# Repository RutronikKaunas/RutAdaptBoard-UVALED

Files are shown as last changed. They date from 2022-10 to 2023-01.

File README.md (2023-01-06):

# RutAdaptBoard-UVA LED Odor Eliminator

This is an odor-eliminator concept. The ultra-high frequency PWM is used to generate UVA light Trichel pulses that are exposing the TiO2 catalyst. The VOC – Volatile Organic Compounds are degrading on the TiO2 catalyst surface down to the harmless and odorless components.

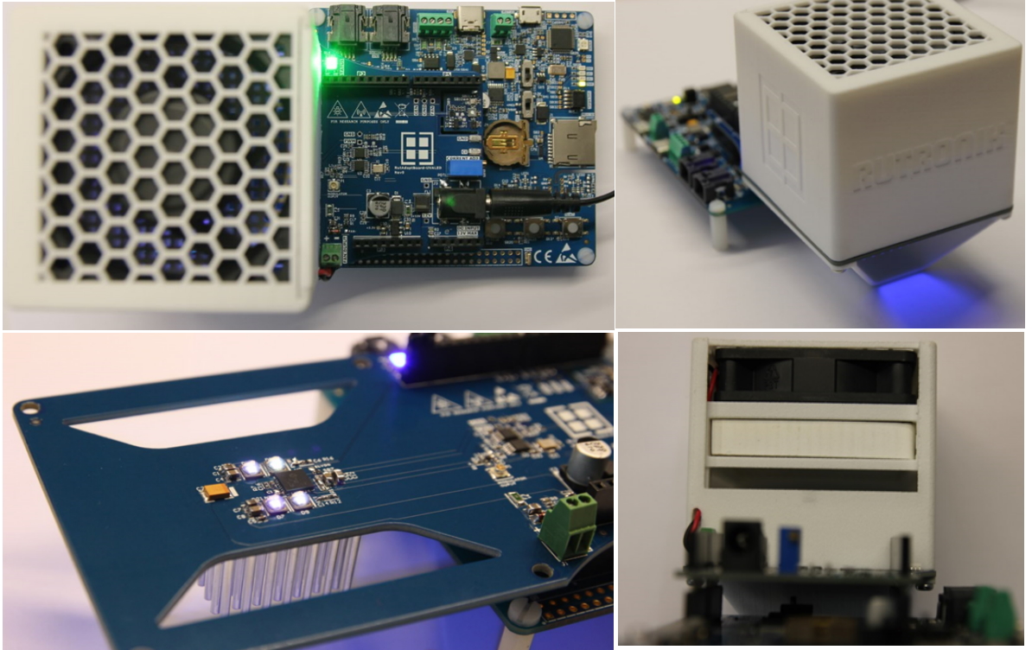
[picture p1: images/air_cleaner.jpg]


## Features

-  iC-HG 200MHz 3A LASER Switch.

-  High Power UVA-LEDs NDU1104ESE-405-TR from Stanley Electric.

-  SI5351A-B-GT - I2C Progrmmable Clock Generator IC.

-  SHTC1 - Sensirion's Humidity and Temperature Sensor IC.

-  SGP30 - Sensirion's Indoor Air Quality Sensor for TVOC and CO2eq Measurements.

-  BMP388 - Digital pressure sensor from BOSCH.

-  DG2733EDQ-T1-GE3 - Low Voltage Dual SPDT Analog Switch from Vishay.

-  AZ1117CR-3.3TRG1 - 3.3V 800mA LDo from Diodes Inc.

-  The heat sink : „ICK S 25*25*18.5“ from Fischer Elektronik.

-  Liteon LTPL- R6060BSH titanium dioxide photocatalyst filter.

-  Delta AFB0612HHB - Fan for airflow control and air cooling of the LEDs.

## Legal Disclaimer

The evaluation board including the software is for testing purposes only and, because it has limited functions and limited resilience, is not suitable for permanent use under real conditions. If the evaluation board is nevertheless used under real conditions, this is done at one’s responsibility; any liability of Rutronik is insofar excluded. 

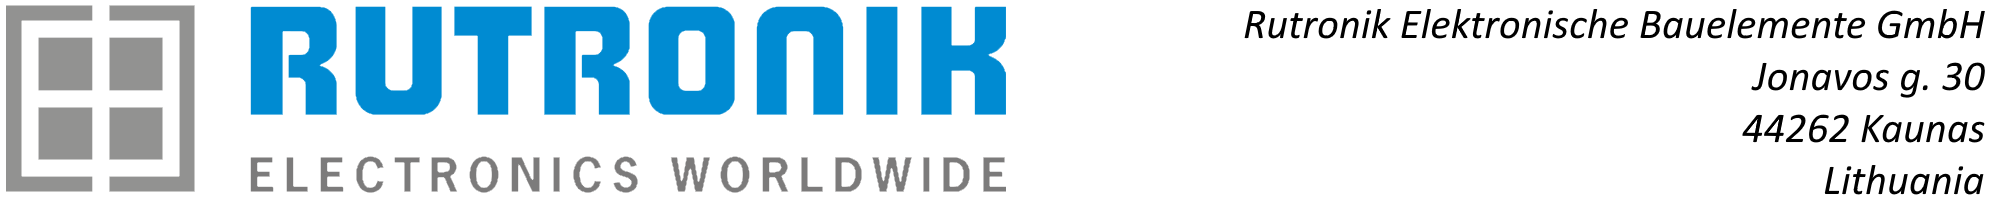
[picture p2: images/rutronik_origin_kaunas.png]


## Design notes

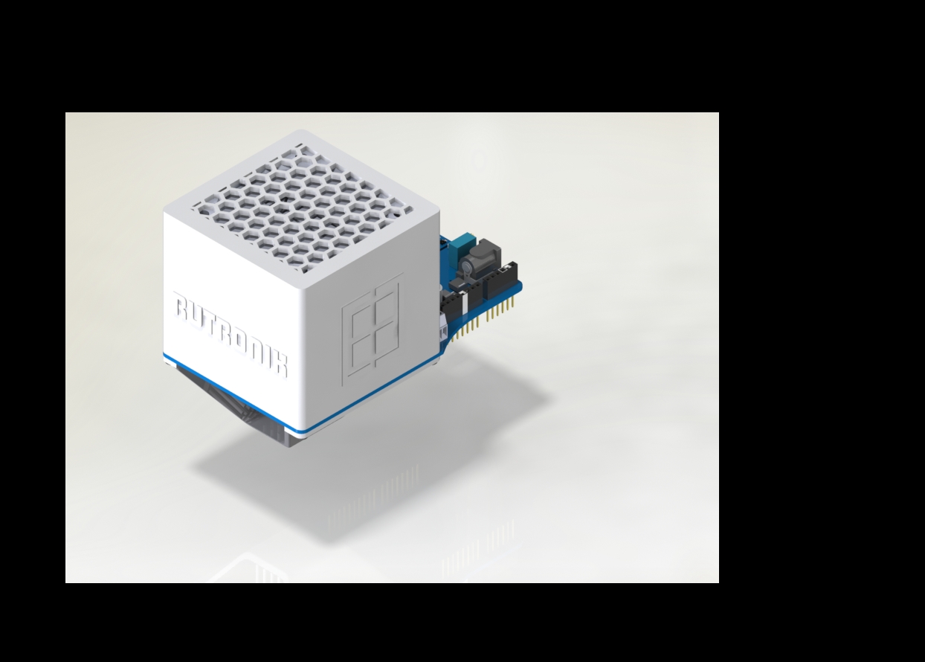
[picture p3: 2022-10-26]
Hardware Design Files/RutAdaptBoard-UVALED Housing/Render/Studio rendering.JPG

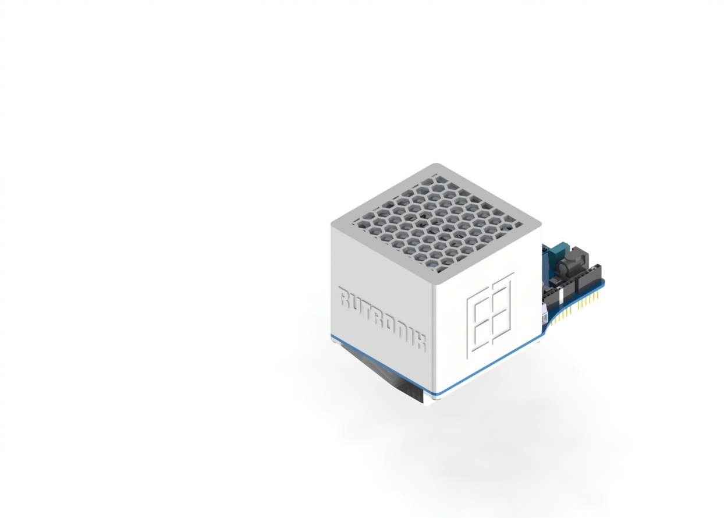
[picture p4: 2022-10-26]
Hardware Design Files/RutAdaptBoard-UVALED Housing/Render/Soft box view.JPG

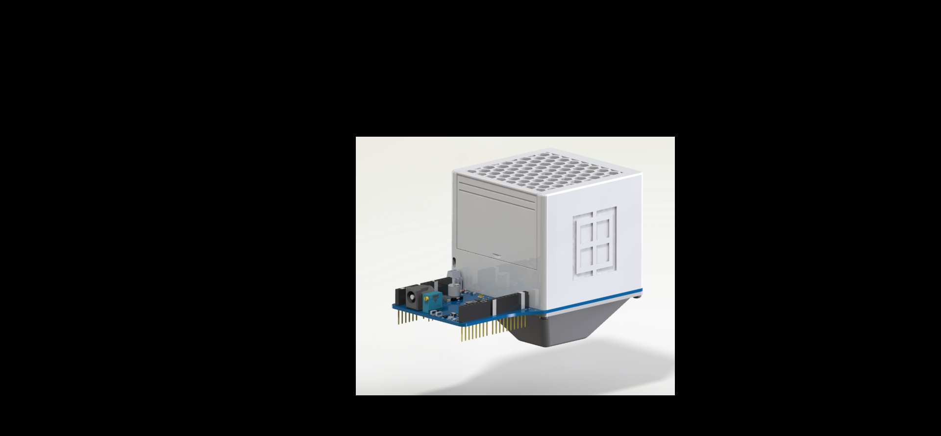
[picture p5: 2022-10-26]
Hardware Design Files/RutAdaptBoard-UVALED Housing/Render/final render_1.JPG

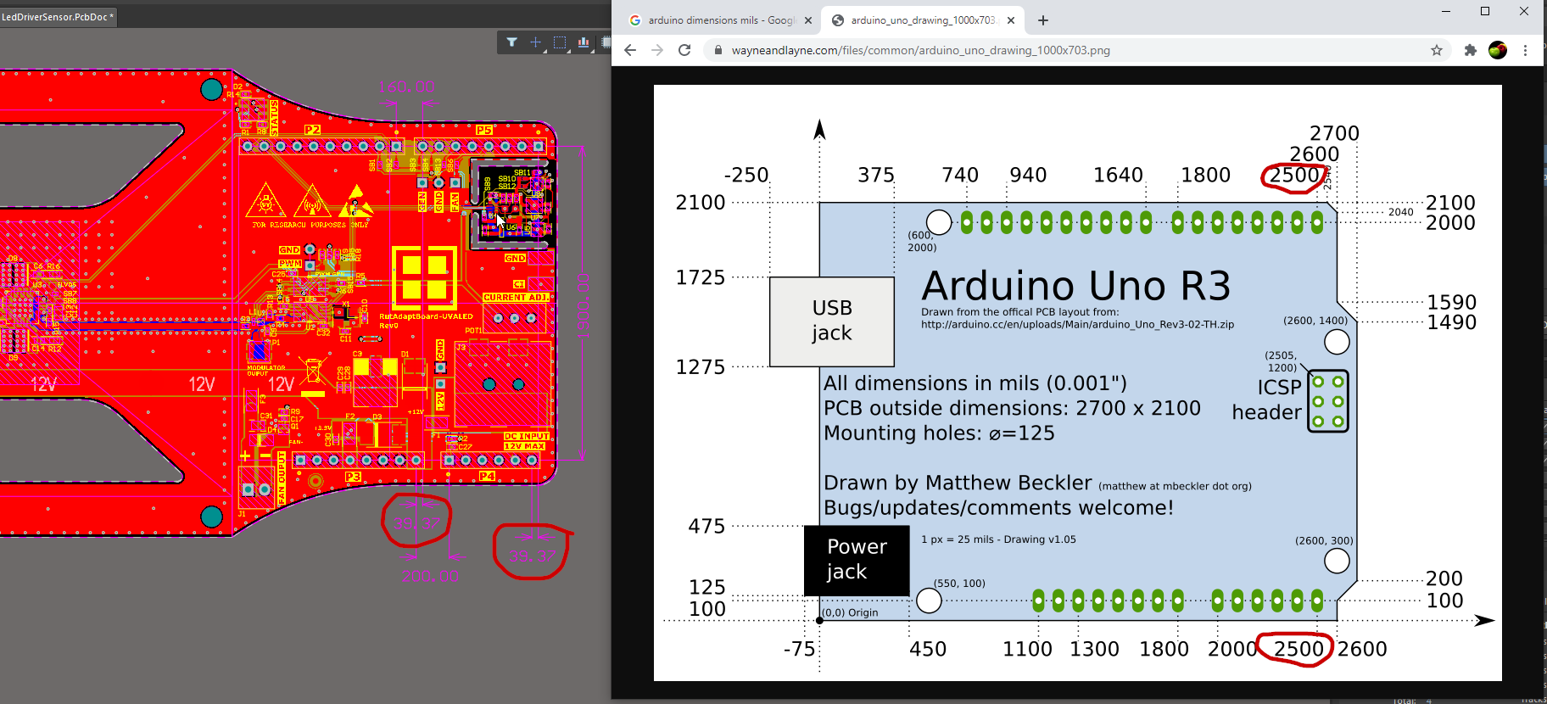
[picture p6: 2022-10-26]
Hardware Design Files/RutAdaptBoard-UVALED Housing/Arduino dimmensions.png

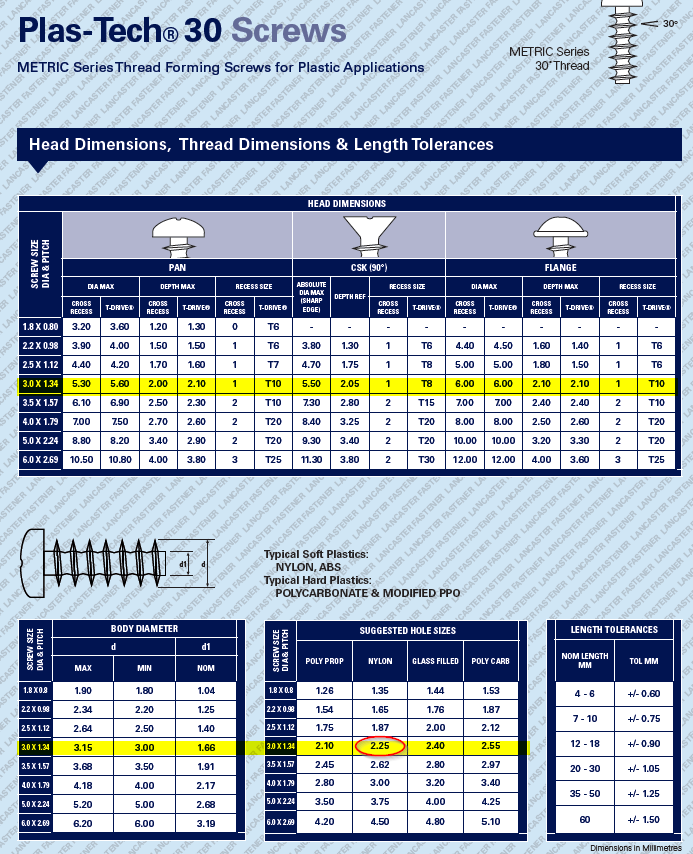
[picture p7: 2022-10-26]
Hardware Design Files/RutAdaptBoard-UVALED Housing/Documentation/Plastech 30 hole size .png

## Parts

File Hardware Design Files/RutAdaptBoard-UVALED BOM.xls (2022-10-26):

RUTADAPTBOARD-UVALED BOM Rev0
Part Description | Specification | Value | Designator | Footprint | Quantity | Manufacturer | Manufacturer Part No. | Supplier | Supplier part number | Link
Ceramic Capacitor | X7R, 16V, 10% | 10uF | C1, C7, C12, C30, C31 | C0805 | 5 | Samsung EM | CL21B106KOQNNNG | Rutronik | KKS2640 | https://www.rutronik24.com/product/samsung+em/cl21b106koqnnng/32265.html
Ceramic Capacitor | X7R, 16V, 10% | 100nF | C2, C5, C9, C13, C15, C16, C18, C19, C20, C23, C24, C25, C27, C28, C32 | C0402 | 15 | Samsung EM | CL05B104KO5NNNC | Rutronik | KKK21419 | https://www.rutronik24.com/product/samsung+em/cl05b104ko5nnnc/4748662.html
Electrolytic Capacitor | 16V, 20% | 330uF | C3 | Cap_6.3_7.7_SMD | 1 | Panasonic | EEE-FTC331XAP | Rutronik | KEL20909 | https://www.rutronik24.com/search-result/qs:EEE-FTC331XAP/reset:0
Ceramic Capacitor | X7R, 16V, 10% | 1uF | C4, C8, C33, C34 | C0805 | 4 | Samsung EM | CL21B105KOFNNNF | Rutronik | KKK16216 | https://www.rutronik24.com/product/samsung+em/cl21b105kofnnnf/30238.html
Ceramic Capacitor | NP0, 50V, 0.25pf | 2.2pF | C10, C11 | C0402 | 2 | Yageo | CC0402CRNPO9BN2R2 | Rutronik | KKK19155 | https://www.rutronik24.com/product/yageo/cc0402crnpo9bn2r2/30956.html
Ceramic Capacitor | NP0, 50V, 5% | 33pF | C17, C29 | C0402 | 2 | Samsung EM | CL05C330JB5NNNC | Rutronik | KKK15073 | https://www.rutronik24.com/product/samsung+em/cl05c330jb5nnnc/29970.html
Ceramic Capacitor | X5R, 16V, 10% | 1uF | C21, C22 | C0402 | 2 | Samsung EM | CL05A105KO5NNNC | Rutronik | KKS1052 | https://www.rutronik24.com/product/samsung+em/cl05a105ko5nnnc/31788.html
Tantalum Polymer Capacitor | 16V, 20% | 33uF | C26 | Case-B | 1 | AVX | TCNL336M016R0200E | Rutronik | TCNL336M016R0200E | https://www.rutronik24.com/search-result/qs:TCNL336M016R0200E/reset:0
TVS Diode | 14V, 0.6kW | SMBJ12A-13-F | D1 | DO-214AA | 1 | Diodes Inc. | SMBJ12A-13-F | Rutronik | DTRL10413 | https://www.rutronik24.com/product/diodes+inc/smbj12a-13-f/10283804.html
RGB LED | 626 nm, 528 nm, 465 nm | LRTBGVSR-U4V2-JW+A6BB-D8+S2U2-7Z-20-S | D2 | PlCC6_led avago | 1 | OSRAM | LRTBGVSR-U4V2-JW+A6BB-D8+S2U2-7Z-20-S | Rutronik | LRTBGVSR-U4V2-JW+A6BB-D8+S2U2-7Z-20-S | https://www.osram.com/ecat/OSIRE%C2%AE%20E3635%20LRTBGVSR/com/en/class_pim_web_catalog_103489/global/prd_pim_device_5154412/
High Power UV-LED | UVA, 405nm, 500mA | NDU1104ESE-405-TR | D5, D7, D8, D9 | NDU1104ESE | 4 | Stanley Electric | NDU1104ESE-405-TR | Rutronik | IR7213 | https://www.rutronik24.com/product/stanley/ndu1104ese-405-tr/12405034.html
High I²t Chip fuse | 32V, 5A | CC12H5A-TR | F1 | R1206 | 1 | EATON | CC12H5A-TR | Rutronik | FUSE7161 | https://www.rutronik24.com/search-result/nojs:1337/qs:CC12H5A-TR/reset:0
High I²t Chip fuse | 63V, 1A | CC12H1A-TR | F3 | R1206 | 1 | EATON | CC12H1A-TR | Rutronik | CC12H1A-TR | https://www.rutronik24.com/search-result/qs:CC12H1A-TR/reset:0
Wire Wound Chip Common Mode Choke Coil | 250R/100MHz | DLW5BTM251SQ2L | FL1 | DLW5BTM | 1 | MuRata | DLW5BTM251SQ2L | Rutronik | IND12787 | https://www.rutronik24.com/product/murata/dlw5btm251sq2l/4718370.html
Pin heatsink quadratic | 25 x 25 x 18,5 mm | ICK S 25x25x18,5 | HS1 | ICKS25x25x18_5 | 1 | Fischer Elektronik | ICK S 25x25x18,5 | Rutronik | HSINK2003 | https://www.rutronik24.com/product/fischer/ick+s+25+x+25+x+18%2C5/12693988.html
Terminal | 2pos. 2.54mm, 12A | MSD02004 | J1 | SAURO_2POS_2.54 | 1 | SAURO | MSD02004 | Rutronik | CONN2626 | https://www.rutronik24.com/search-result/nojs:1337/qs:MSD02004/reset:0
Low Voltage Power Supply Connector | 20V, 5A | ADC-028-1-T/R-PA10T | J3 | DC_JACK_ADC-028-1 | 1 | ADAM TECH | ADC-028-1-T/R-PA10T | Rutronik | CONN1349 | https://www.rutronik24.com/search-result/qs:ADC-028-1/reset:0
Inductor | 150mA 5% | 100nH | L1 | L0402 | 1 | muRata | LQG15WHR10J02D | Rutronik | LQG15WHR10J02D | https://www.rutronik24.com/search-result/qs:LQG15WHR10J02D/reset:0
U.FL Connector | Male | U.FL-R-SMT-1(10) | P1 | U.FL_Connector_Male | 1 | HIROSE | U.FL-R-SMT-1(10) | Rutronik | COREC23028 | https://www.hirose.com/product/en/products/U.FL/U.FL-R-SMT-1%2810%29/
Arduino Connector | 10 pos. 2,54mm | RS1-10-G-413 | P2 | HDR1X10_ARDUINO | 1 | ADAM TECH | RS1-10-G-413 | Rutronik | CONN1443 | http://www.adam-tech.com/products.php
Arduino Connector | 8 pos. 2,54mm | RS1-08-G-413 | P3, P5 | HDR1X8_ARDUINO | 2 | ADAM TECH | RS1-08-G-413 | Rutronik | CONN2043 | http://www.adam-tech.com/products.php
Arduino Connector | 6 pos. 2,54mm | RS1-06-G-413 | P4 | HDR1X6_ARDUINO | 1 | ADAM TECH | RS1-06-G-413 | Rutronik | CONN2042 | http://www.adam-tech.com/products.php
Trimmer | 10% 0,5W | 10K | POT1 | T93XA | 1 | Vishay | T93XA103KT20 | Rutronik | T93XA103KT20 | https://www.rutronik24.com/search-result/qs:T93XA103KT20/reset:0
N-Channel MOSFET | 20V, 0.63A | DMG1012T-7 | Q1 | SOT-523_custom | 1 | Diodes Inc. | DMG1012T-7 | Rutronik | TMOSS6623 | https://www.rutronik24.com/product/diodes+inc/dmg1012t-7/5168665.html
Thick Film Resistor | 5% 0,063W | 220R | R1, R8, R14 | R0402 | 3 | ASJ | RC0402JR-0710KL | Rutronik | WRC35108 | https://www.rutronik24.com/product/asj/cr10-221-jk/51883.html
Thick Film Resistor | 5% 0,063W | 10K | R2, R9, R18, R19 | R0402 | 4 | ASJ | CR10-103-JK | Rutronik | WRC40976 | https://www.rutronik24.com/product/asj/cr10-103-jk/54295.html
Thick Film Resistor | 5% 0,063W | 0R | R3, R4 | R0402 | 2 | Yageo | RC04020R | Rutronik | WRC52534 | https://www.rutronik24.com/product/yageo/ac0402fr-070rl/1082692.html
Thick Film Resistor | 5% 0,063W | 4.7K | R5, R6 | R0402 | 2 | Yageo | RC0402JR-134K7L | Rutronik | WRC46913 | https://www.rutronik24.com/product/yageo/rc0402jr-134k7l/56100.html
Thick Film Resistor | 5% 0,063W | 1K | R7 | R0402 | 1 | Yageo | RC0402JR-071KL | Rutronik | WRC33833 | https://www.rutronik24.com/search-result/nojs:1337/qs:RC0402JR-071KL/reset:0
NTC Thermistor | 3% 0,1W | NTCG103UH103HT1 | R21 | 0402NTC | 1 | TDK | NTCG103UH103HT1 | Rutronik | NTCG103UH103HT1 | https://www.rutronik24.com/search-result/qs:NTCG103UH103HT1/reset:0
Thick Film Resistor | 5% 0,063W | 0R | SB1, SB2, SB5, SB6, SB7, SB9, SB11, SB13 | SB_0402 | 8 | Yageo | RC04020R | Rutronik | WRC52534 | https://www.rutronik24.com/product/yageo/ac0402fr-070rl/1082692.html
SMT Test Point | 3.81*2.03 | 5019 | TP2, TP3 | 5019_keystone | 2 | Keystone Electrincs | 5019 | Rutronik | BAT4950 | https://www.rutronik24.com/product/keystone/pn5019/7028403.html
2-Input AND Gate | 3.3V, 2.5ns | 7UL1G08FS,LF | U1 | SOT-953 | 1 | TOSHIBA | 7UL1G08FS,LF | Rutronik | 7UL1G08FSLFCT-ND | https://toshiba.semicon-storage.com/ap-en/semiconductor/product/general-purpose-logic-ics/detail.7UL1G08FS.html
I2C-PROGRAMMABLE CLOCK | 200MHz, 3.3V | SI5351A-B-GT | U2 | MSOP10 | 1 | Silicon Labs | SI5351A-B-GT | Digi-Key | 336-2399-5-ND | https://www.digikey.com/en/products/detail/silicon-labs/SI5351A-B-GT/3679847
3 A LASER SWITCH | 200MHz, 3A | iC-HG | U3 | QFN28-5x5 | 1 | iC Haus | iC-HG | Rutronik | iC-HG | https://www.ichaus.de/product/iC-HG
2-Bit Bi-directional Level Shifter | 8UDFN | PI4ULS5V202XVEX | U4 | UDFN1.2x1.6-8L | 1 | Diodes Inc. | PI4ULS5V202XVEX | Rutronik | PI4ULS5V202XVEX | https://www.diodes.com/part/view/PI4ULS5V202
Humidity and Temperature Sensor IC | 1.8V, I2C | SHTC1 | U5 | SHTC1 | 1 | Sensirion | SHTC1 | Rutronik | ICENVI1113 | https://www.rutronik24.com/product/sensirion/shtc1/9854425.html
150mA ULTRA-LOW QUIESCENT CURRENT LDO WITH ENABLE | 5.5V,1.8V,150mA | AP7354-18W5-7 | U6 | SOT23-5L | 1 | Diodes Inc. | AP7354-18W5-7 | Rutronik | AP7354-18W5-7 | https://www.rutronik24.com/search-result/qs:AP7354-18W5-7/reset:0
Indoor Air Quality Sensor for TVOC and CO2eq Measurements | 1.8V, I2C | SGP30 | U7 | SGP30 | 1 | Sensirion | SGP30 | Rutronik | ICENVI1053 | https://www.rutronik24.com/product/sensirion/sgp30/8537405.html
Digital pressure sensor | 1.8V, I2C, SPI | BMP388 | U8 | BMP388 | 1 | BOSCH | BMP388 | Rutronik | ICENVI1143 | https://www.rutronik24.com/product/bosch+se/bmp388/10280357.html
Low Voltage Dual SPDT Analog Switch | 0.3Ohm, Dual SPDT | DG2733EDQ-T1-GE3 | U9 | MSOP10 | 1 | Vishay | DG2733EDQ-T1-GE3 | Rutronik | DG2733EDQ-T1-GE3 | https://www.vishay.com/docs/75646/dg2535e_dg2733e.pdf
LOW DROPOUT LINEAR REGULATOR | 18V, 3.3V, 0.8A | AZ1117CR-3.3TRG1 | U10 | SOT89 | 1 | Diodes Inc. | AZ1117CR-3.3TRG1 | Rutronik | ICSPR9803 | https://www.rutronik24.com/search-result/qs:AZ1117CR-3.3TRG1/reset:0
XTAL 3.2x2.5mm | 25MHz, | C7M2500012AEHHF0-RE02 | X1 | XTAL_3.5x2.5 | 1 | HKC Europe | C7M2500012AEHHF0-RE02 | Rutronik | QUARZ6470 | https://www.rutronik24.com/product/hkc/c7m2500012aehhf0-re02/6739407.html

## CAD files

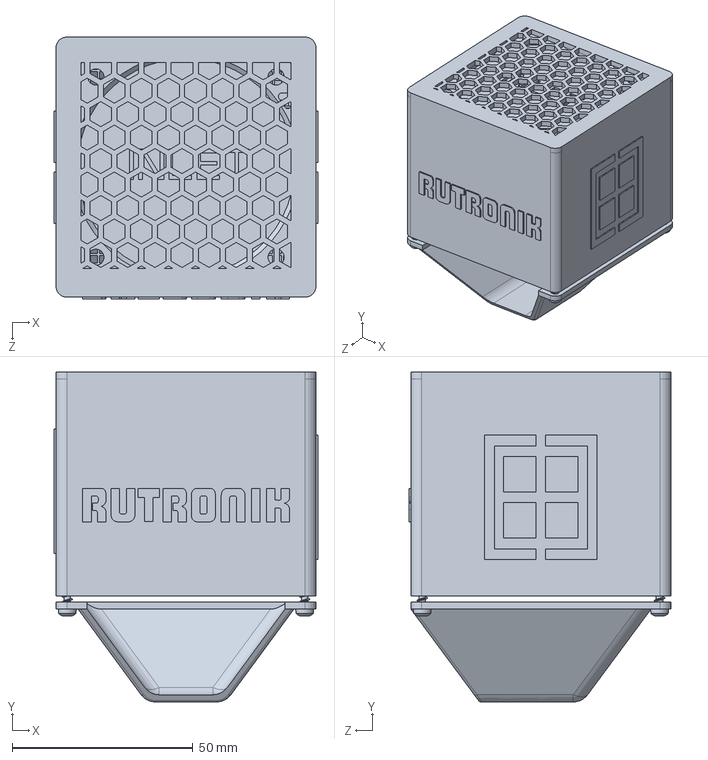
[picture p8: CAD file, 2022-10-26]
Hardware Design Files/RutAdaptBoard-UVALED Housing/Case_assembly_4altium.SLDPRT
73.0 x 91.3 x 72.5 mm

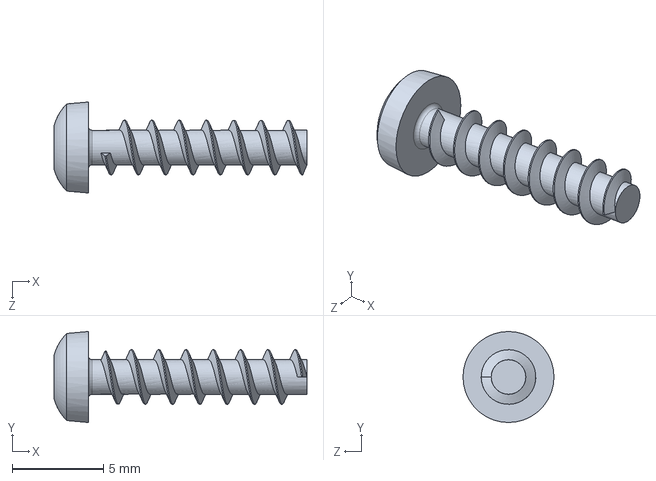
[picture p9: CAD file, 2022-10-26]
Hardware Design Files/RutAdaptBoard-UVALED Housing/TR Fastenings Ltd-3MMX12MM.SLDPRT
13.9 x 5.00 x 5.00 mm

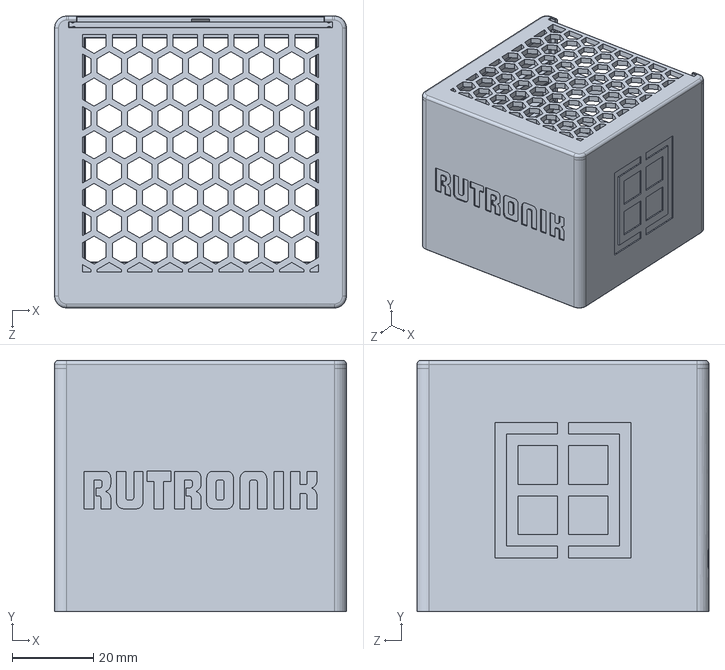
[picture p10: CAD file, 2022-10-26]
Hardware Design Files/RutAdaptBoard-UVALED Housing/Case.SLDPRT
72.0 x 62.0 x 72.0 mm

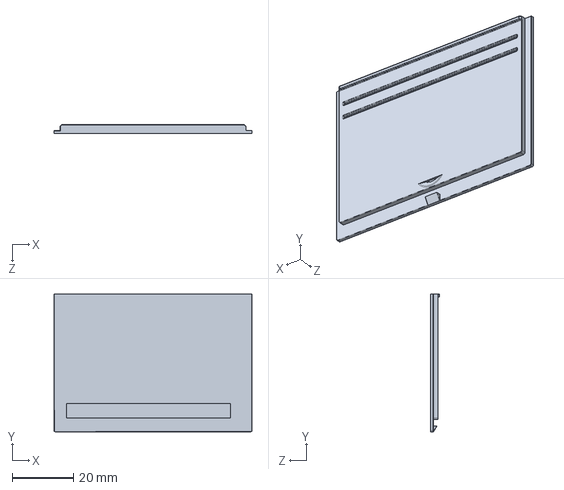
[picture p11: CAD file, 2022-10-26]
Hardware Design Files/RutAdaptBoard-UVALED Housing/LID.SLDPRT
64.6 x 45.0 x 3.00 mm

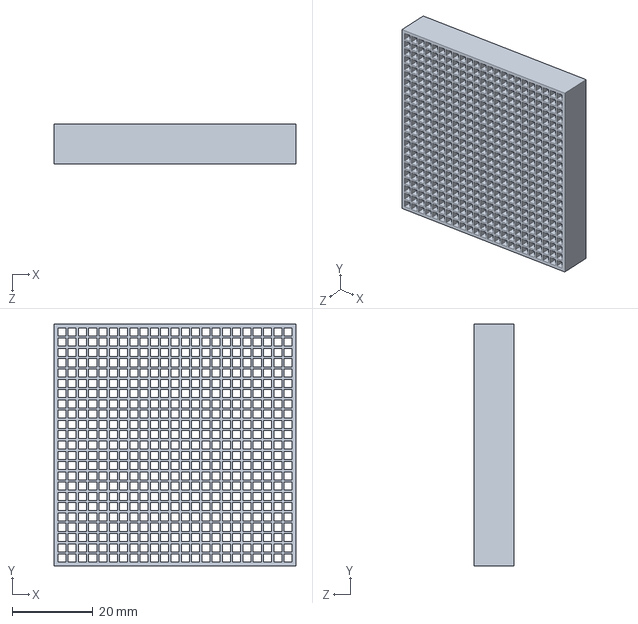
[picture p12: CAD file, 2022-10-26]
Hardware Design Files/RutAdaptBoard-UVALED Housing/LTPL-R6060BSH.SLDPRT
60.0 x 60.0 x 10.0 mm

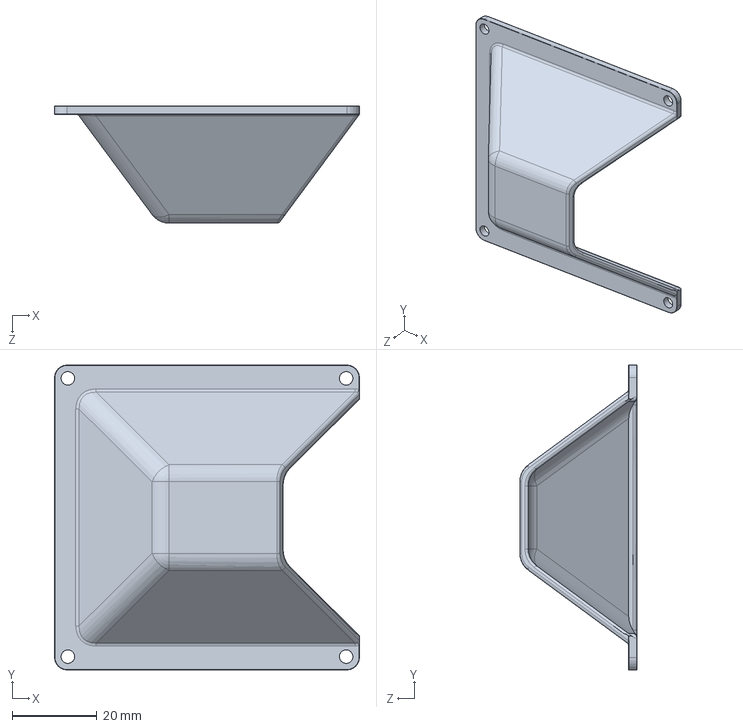
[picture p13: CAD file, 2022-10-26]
Hardware Design Files/RutAdaptBoard-UVALED Housing/Deflector.SLDPRT
72.0 x 72.0 x 27.7 mm

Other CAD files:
Hardware Design Files/RutAdaptBoard-UVALED Housing/Part4.SLDPRT
Hardware Design Files/RutAdaptBoard-UVALED Housing/Board-Part-1.SLDPRT
Hardware Design Files/RutAdaptBoard-UVALED Housing/3D print REV.0/Case.x_t
Hardware Design Files/RutAdaptBoard-UVALED Housing/3D print REV.0/Case_assembly_REV_0.x_t
Hardware Design Files/RutAdaptBoard-UVALED Housing/3D print REV.0/Deflector.x_t
Hardware Design Files/RutAdaptBoard-UVALED Housing/3D print REV.0/LID.x_t
Hardware Design Files/RutAdaptBoard-UVALED Housing/3D print REV0.1/Case.x_t
Hardware Design Files/RutAdaptBoard-UVALED Housing/3D print REV0.1/Deflector.x_t
Hardware Design Files/RutAdaptBoard-UVALED Housing/3D print REV0.1/LID.x_t
Hardware Design Files/RutAdaptBoard-UVALED Housing/Case.x_t
Hardware Design Files/RutAdaptBoard-UVALED Housing/Case_assembly_12.08.x_t
Hardware Design Files/RutAdaptBoard-UVALED Housing/Draw2.SLDDRW
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

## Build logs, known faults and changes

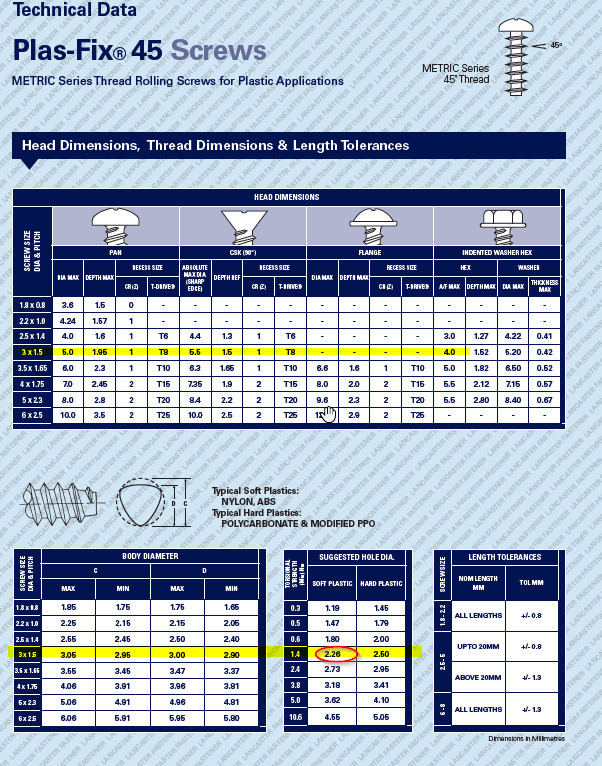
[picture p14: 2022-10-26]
Hardware Design Files/RutAdaptBoard-UVALED Housing/Documentation/Plas-Fix 45 hole size .png

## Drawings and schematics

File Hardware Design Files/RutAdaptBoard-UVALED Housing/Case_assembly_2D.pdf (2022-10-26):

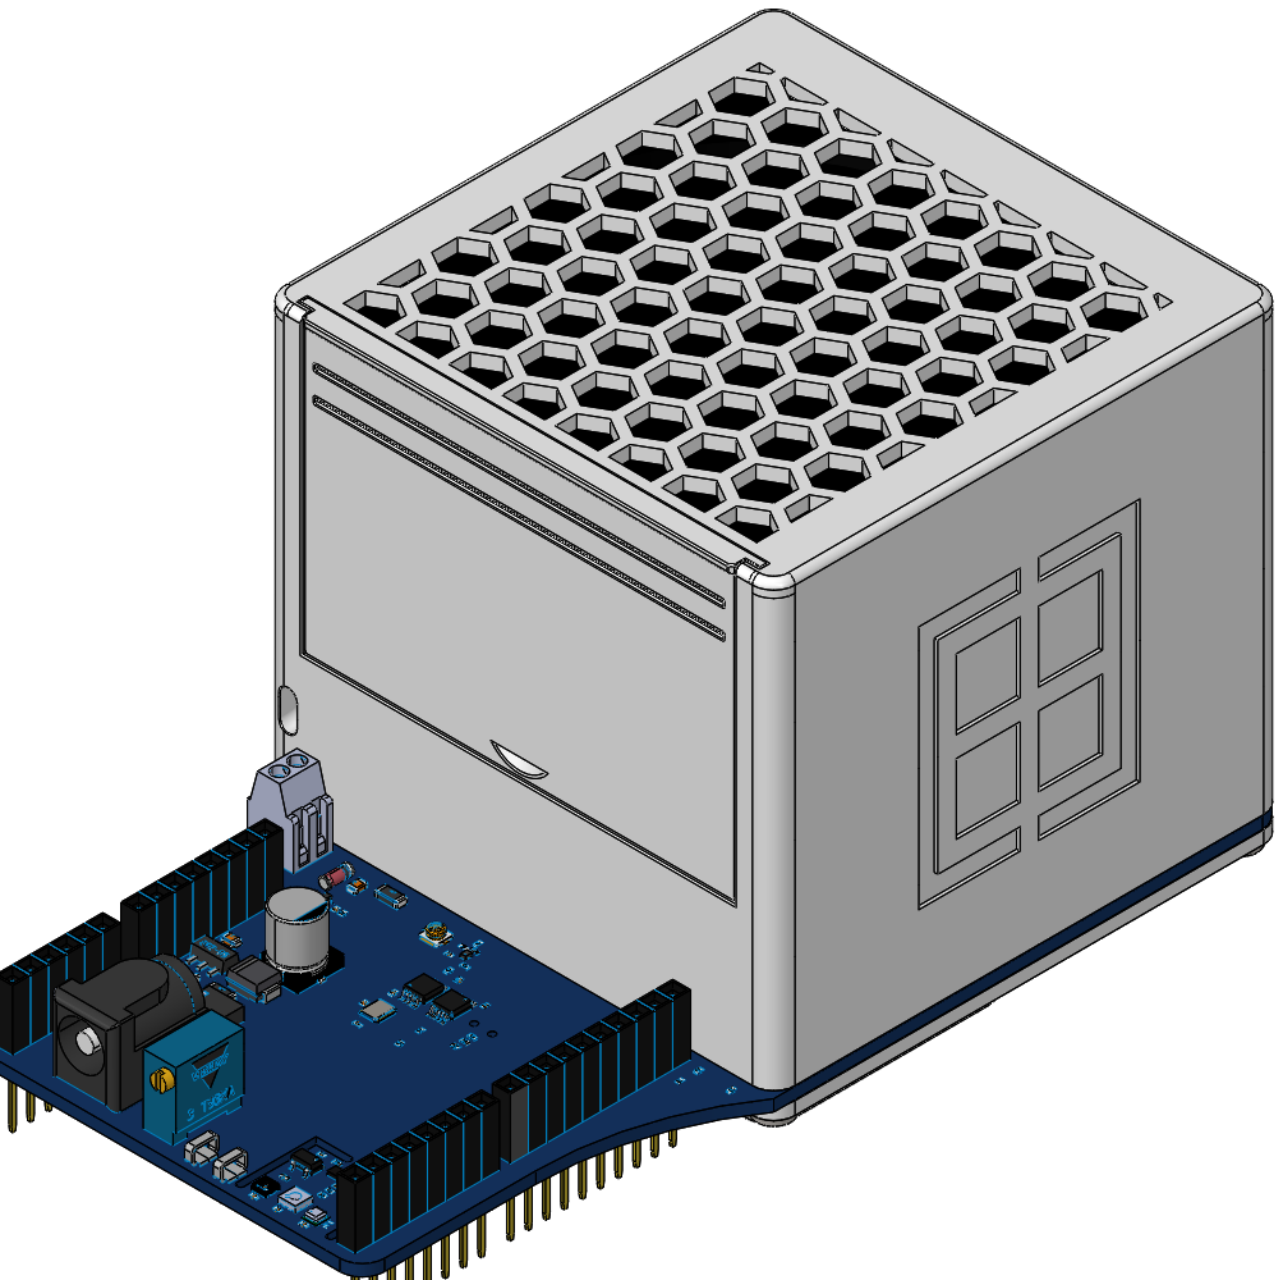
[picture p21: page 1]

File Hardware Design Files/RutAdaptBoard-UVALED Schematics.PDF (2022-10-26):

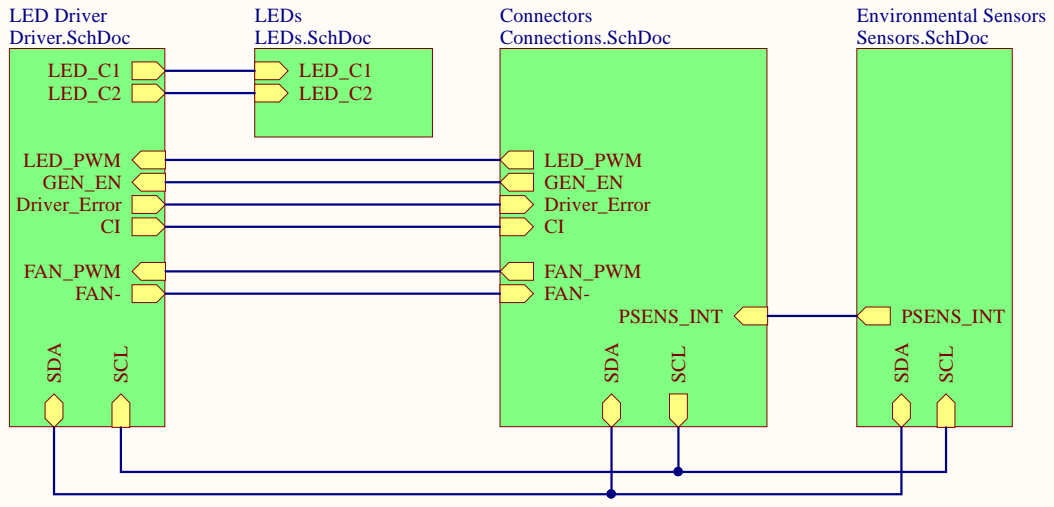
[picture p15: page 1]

RutAdaptBoard-UVProject_General Title | * * *

Size: A4 | Number: | Revision:
Date: 2020-12-03 Time: 13:52:15 | | Sheet of

C:\Users\gdr\Documents\GitHub\RutAppKit-LedDriverSensor\RutAppKit-LedDriverSensor\General.SchDot

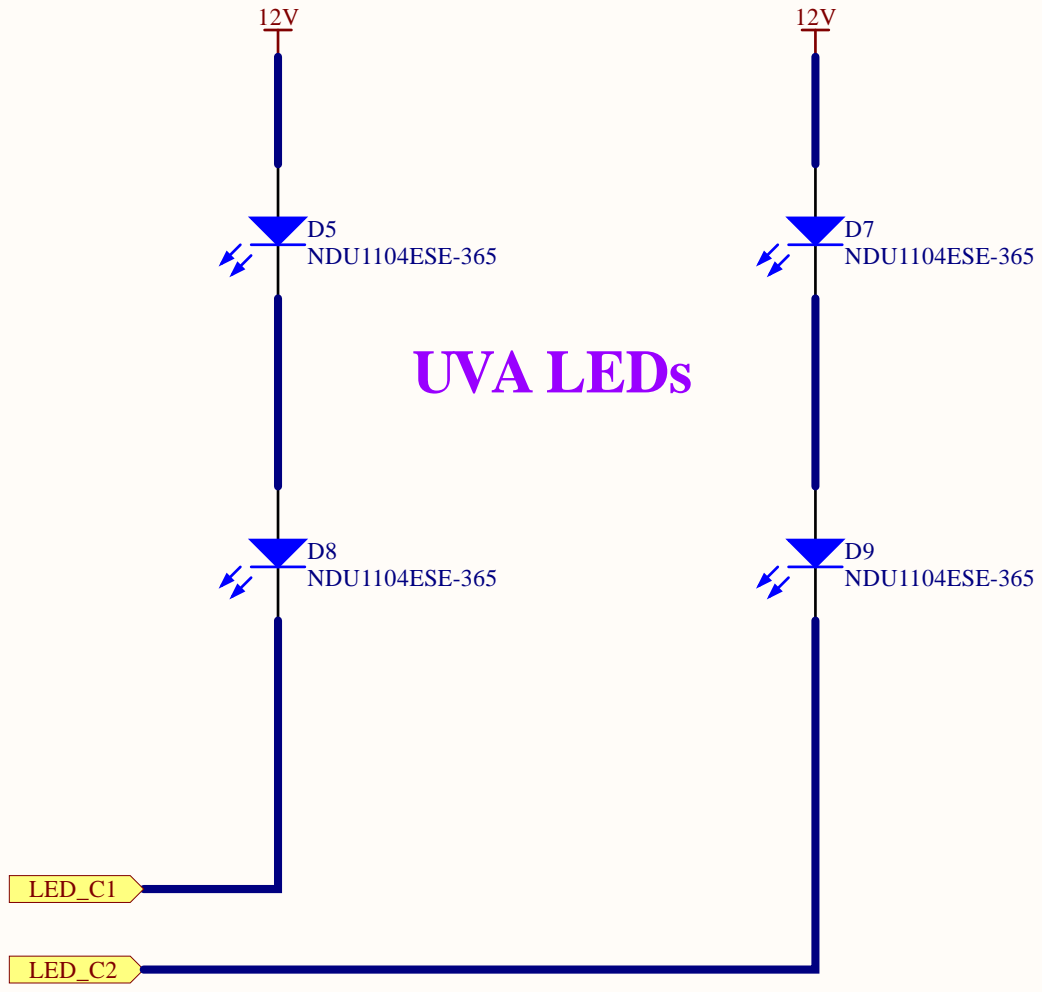
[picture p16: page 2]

LED s T i t l e | ****

Size: A | N umber: | Rev i s i o n :

0-1 2-0 T ime: : : | | Sheet o f

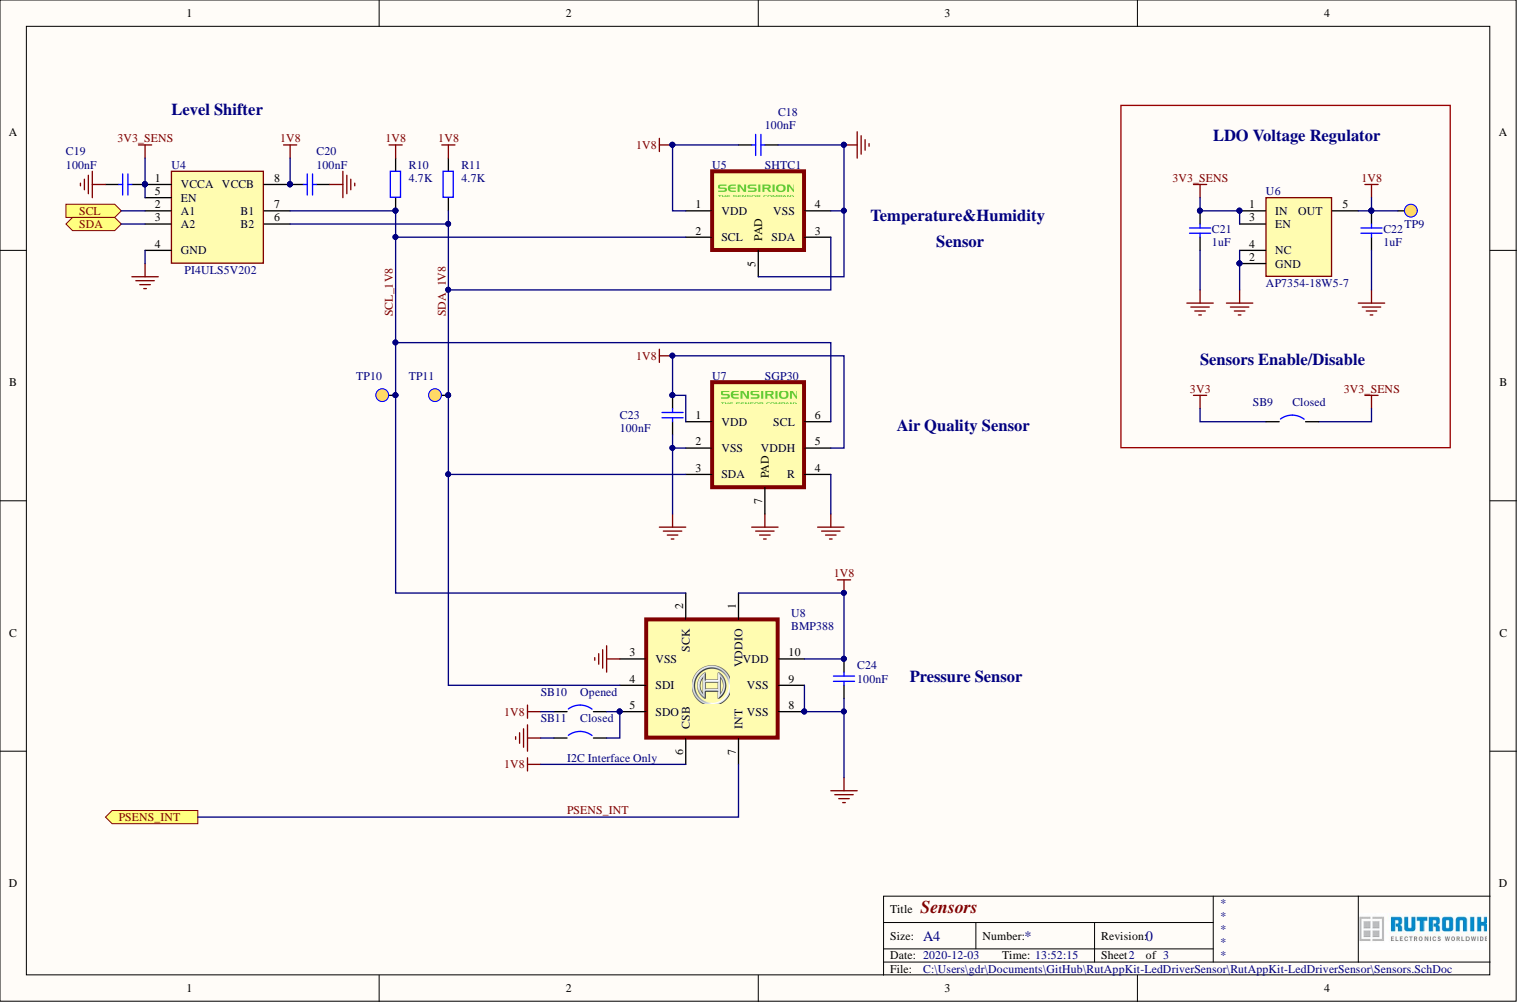
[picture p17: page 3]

C23
100nF | VSS 2

C:\Users\gdr\Documents\GitHub\RutAppKit-LedDriverSensor\RutAppKit-LedDriverSensor\Sensors.SchDoc

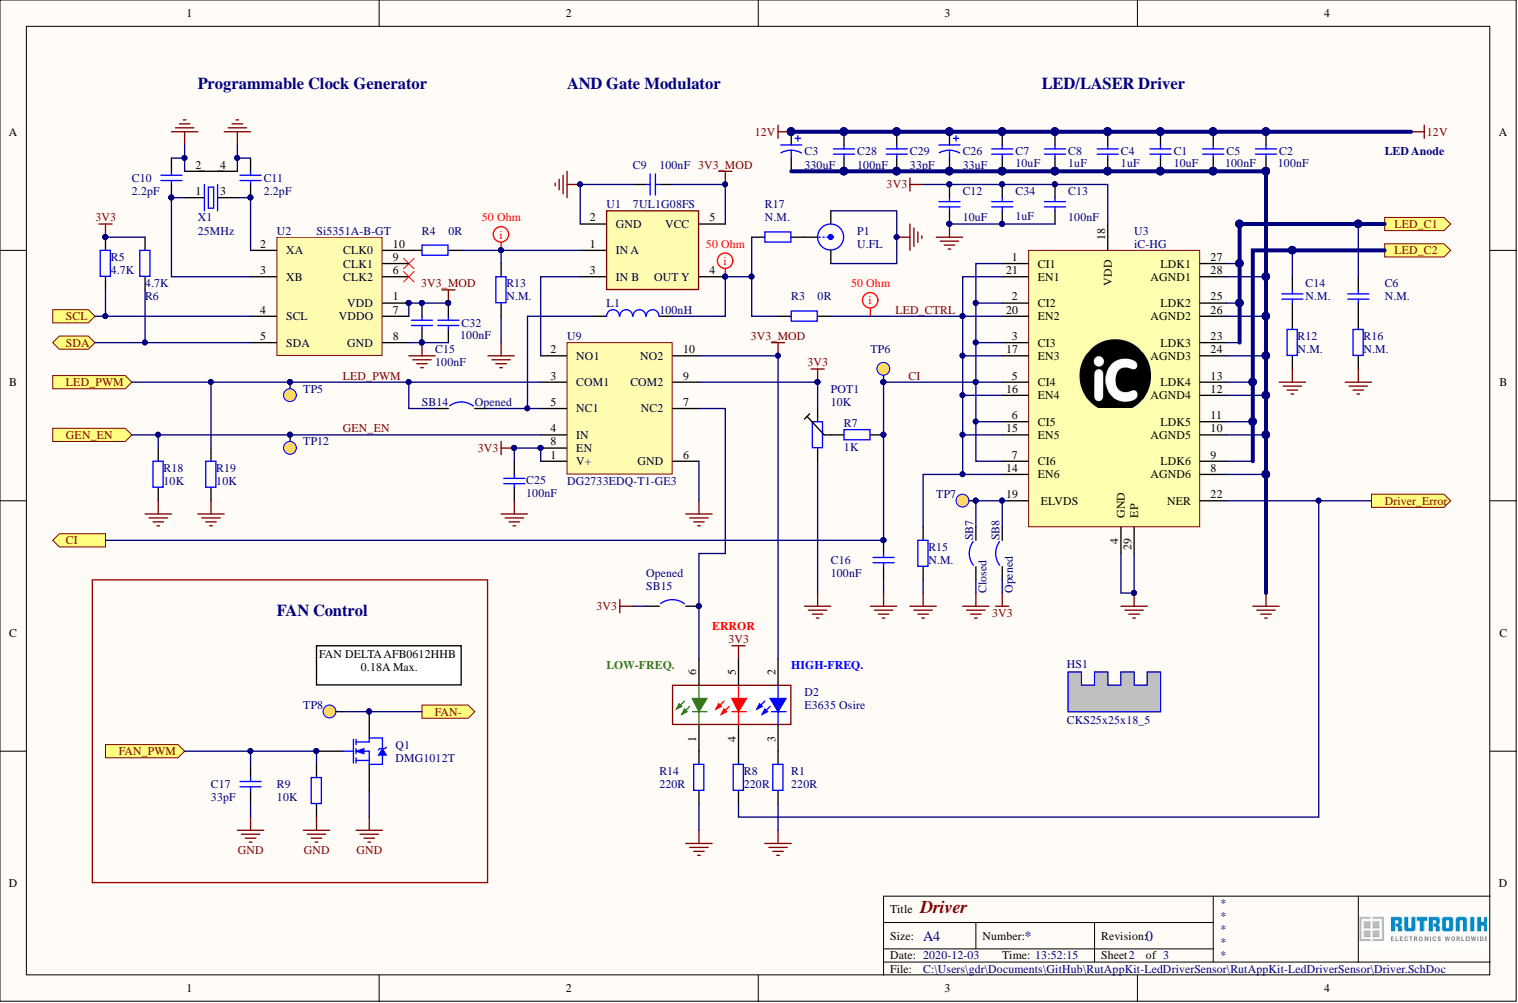
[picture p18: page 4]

C:\Users\gdr\Documents\GitHub\RutAppKit-LedDriverSensor\RutAppKit-LedDriverSensor\Driver.SchDoc

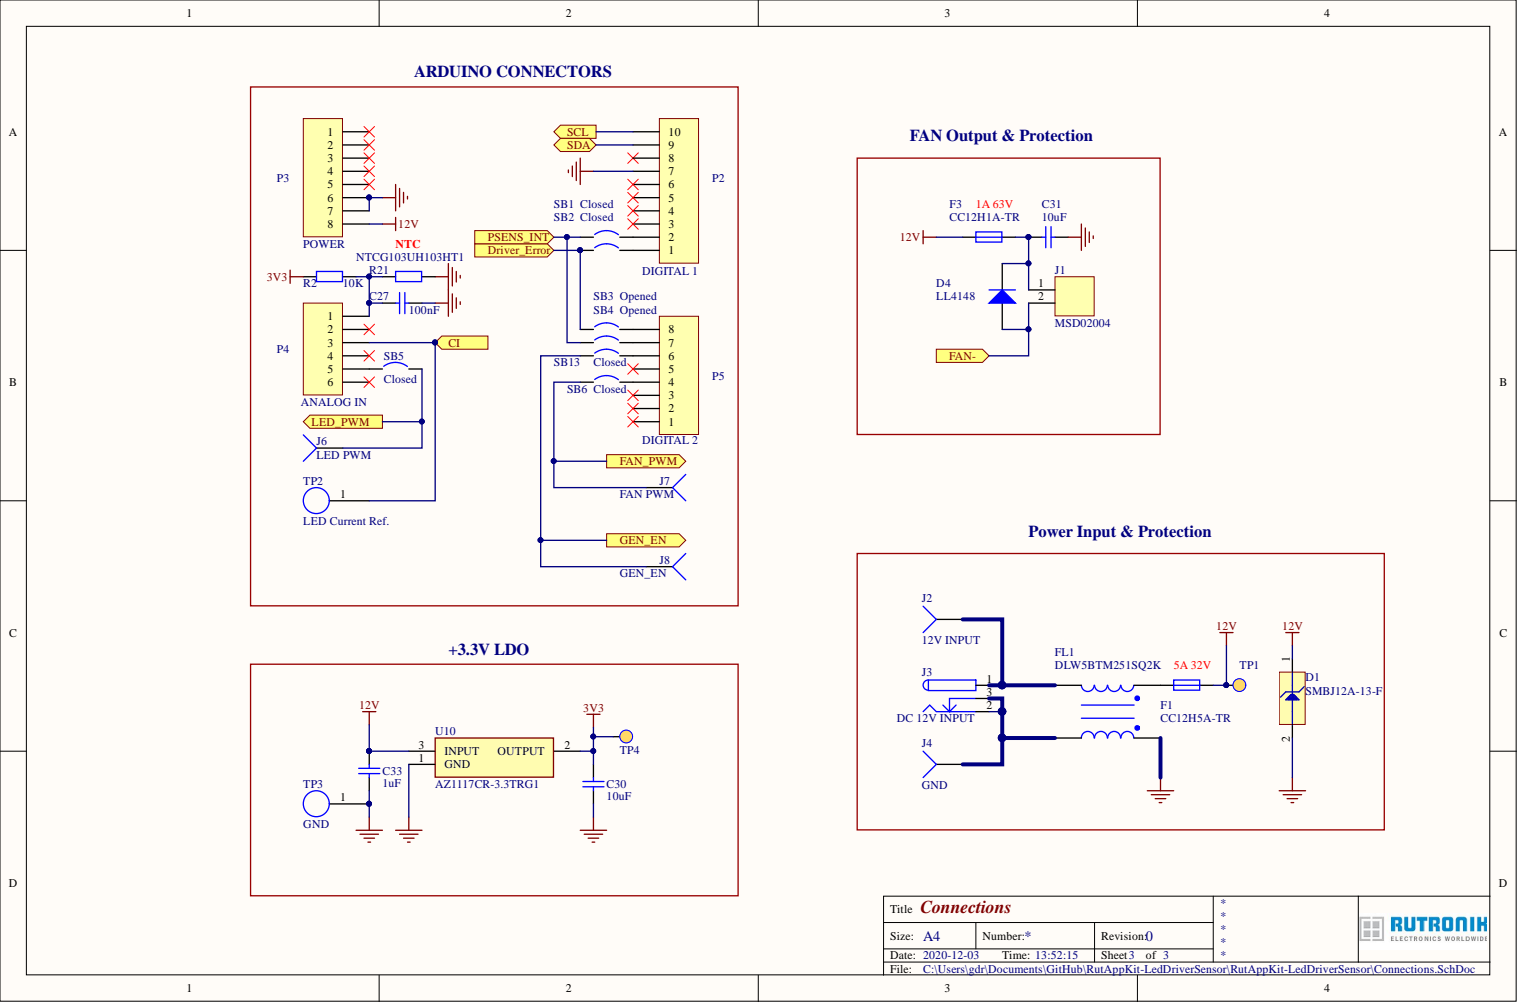
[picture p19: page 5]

Closed

C:\Users\gdr\Documents\GitHub\RutAppKit-LedDriverSensor\RutAppKit-LedDriverSensor\Connections.SchDoc

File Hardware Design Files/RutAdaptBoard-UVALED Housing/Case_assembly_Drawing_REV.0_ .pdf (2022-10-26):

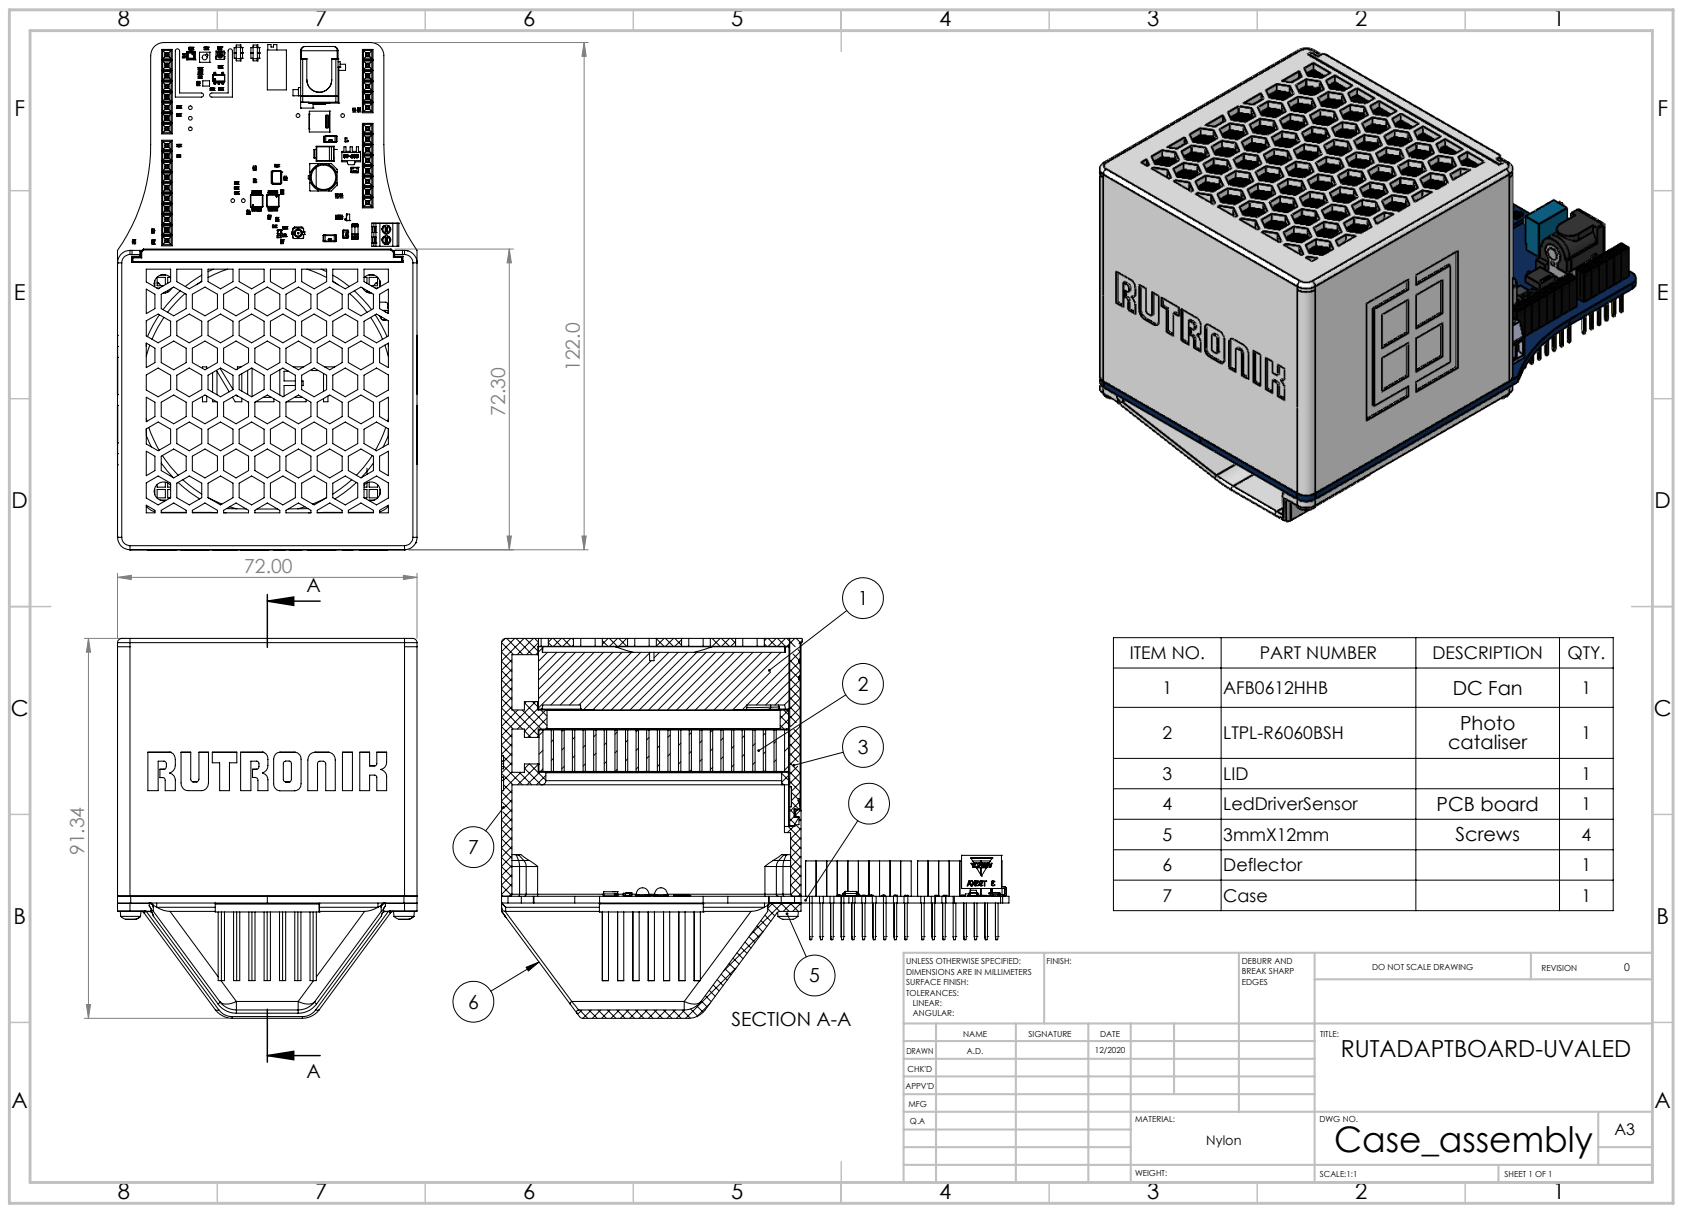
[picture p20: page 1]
SECTION A-A; FINISH:; DEBURR AND; BREAK SHARP; DO NOT SCALE DRAWING; REVISION; SCALE:1:1; SHEET 1 OF 1

ITEM NO. | PART NUMBER | DESCRIPTION | QTY.
1 | AFB0612HHB | DC Fan | 1
2 | LTPL-R6060BSH | Photo cataliser | 1

3 | LID | | 1
4 | LedDriverSensor | PCB board | 1
5 | 3mmX12mm | Screws | 4
6 | Deflector | | 1
7 | Case | | 1

UNLESS OTHERWISE SPECIFIED:
DIMENSIONS ARE IN MILLIMETERS
SURFACE FINISH:
TOLERANCES:
LINEAR:
ANGULAR:

NAME | SIGNATURE | DATE | | | | TITLE: RUTADAPTBOARD-UVALED

DRAWN | A.D. | | 12/2020
CHK'D
APPV'D
MFG
Q.A | | | | MATERIAL: | DWG NO. Case_assembly | A3 Nylon
